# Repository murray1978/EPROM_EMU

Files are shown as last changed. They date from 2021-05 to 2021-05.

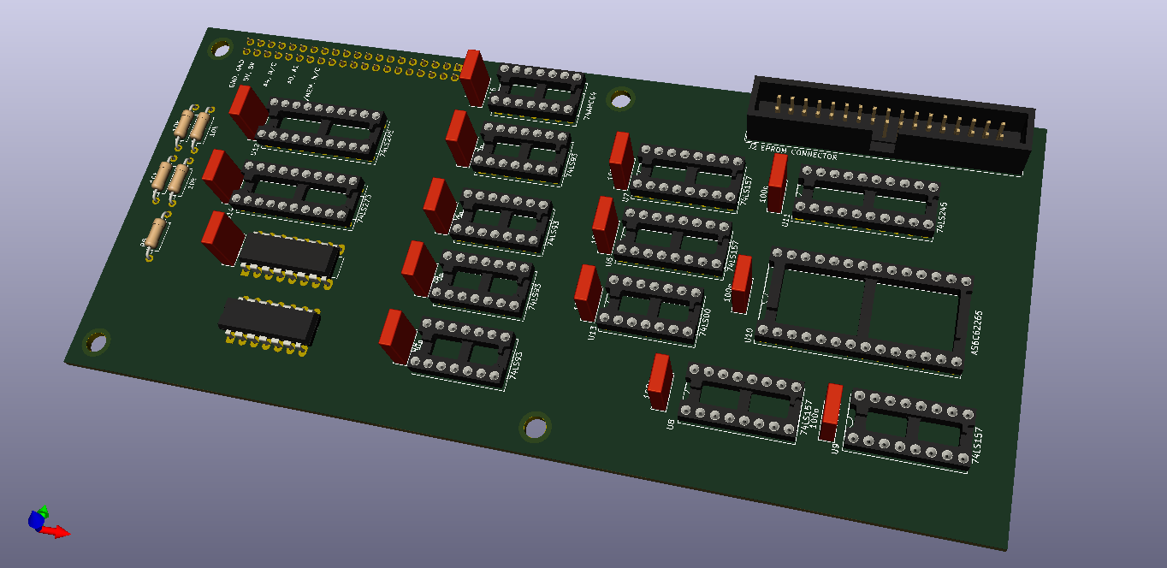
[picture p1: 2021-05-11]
Version 2/wmuv1.1.png

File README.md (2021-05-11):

# EPROM_EMU
EPROM Emulator for [Sergey's](http://www.malinov.com/Home/sergeys-projects/minimax8085) 8085 board.
Second revison is in progress, 12/5/21, check the readme in version two for errors on the board.

## Programming
The monitor rom can be used to upload the emulator code for the board.
Install the battery backup on to the 8085 borad then you will not need to upload each time you need to use the board.

## Source
As is where is, one carfull lady owner.
Some functions are copied from the monitor code, but it does relie on the monitor rom to setup the 8251 UART before use.
Code is just an outline now with a few ideas in comments.

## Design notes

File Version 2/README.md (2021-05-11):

# EPROM_EMU
EPROM Emulator for [Sergey's](http://www.malinov.com/Home/sergeys-projects/minimax8085) 8085 board, This is the Second revision.

## Mistakes
1. IC1 (74LS137), Pins 9 and 7, will never get triggered, the correct connections are pins 15 and 14.
   Fix with a solder a jumper bridge between 9 to 15 and 7 to 14. Schmatic is correct

## Substitutions 
1. U1 can be replaced with a 74LS138
2. the RAM, U10 as6c62256, can be replaced with cy62256? need to confirm pinout.

## Programming
The monitor rom can be used to upload the emulator code for the board.
Install the battery backup on to the 8085 borad then you will not need to upload each time you need to use the board.

## Source
As is where is, one carfull lady owner.
Some functions are copied from the monitor code, but it does relie on the monitor rom to setup the 8251 UART before use.
Code is just an outline now with a few ideas in comments.

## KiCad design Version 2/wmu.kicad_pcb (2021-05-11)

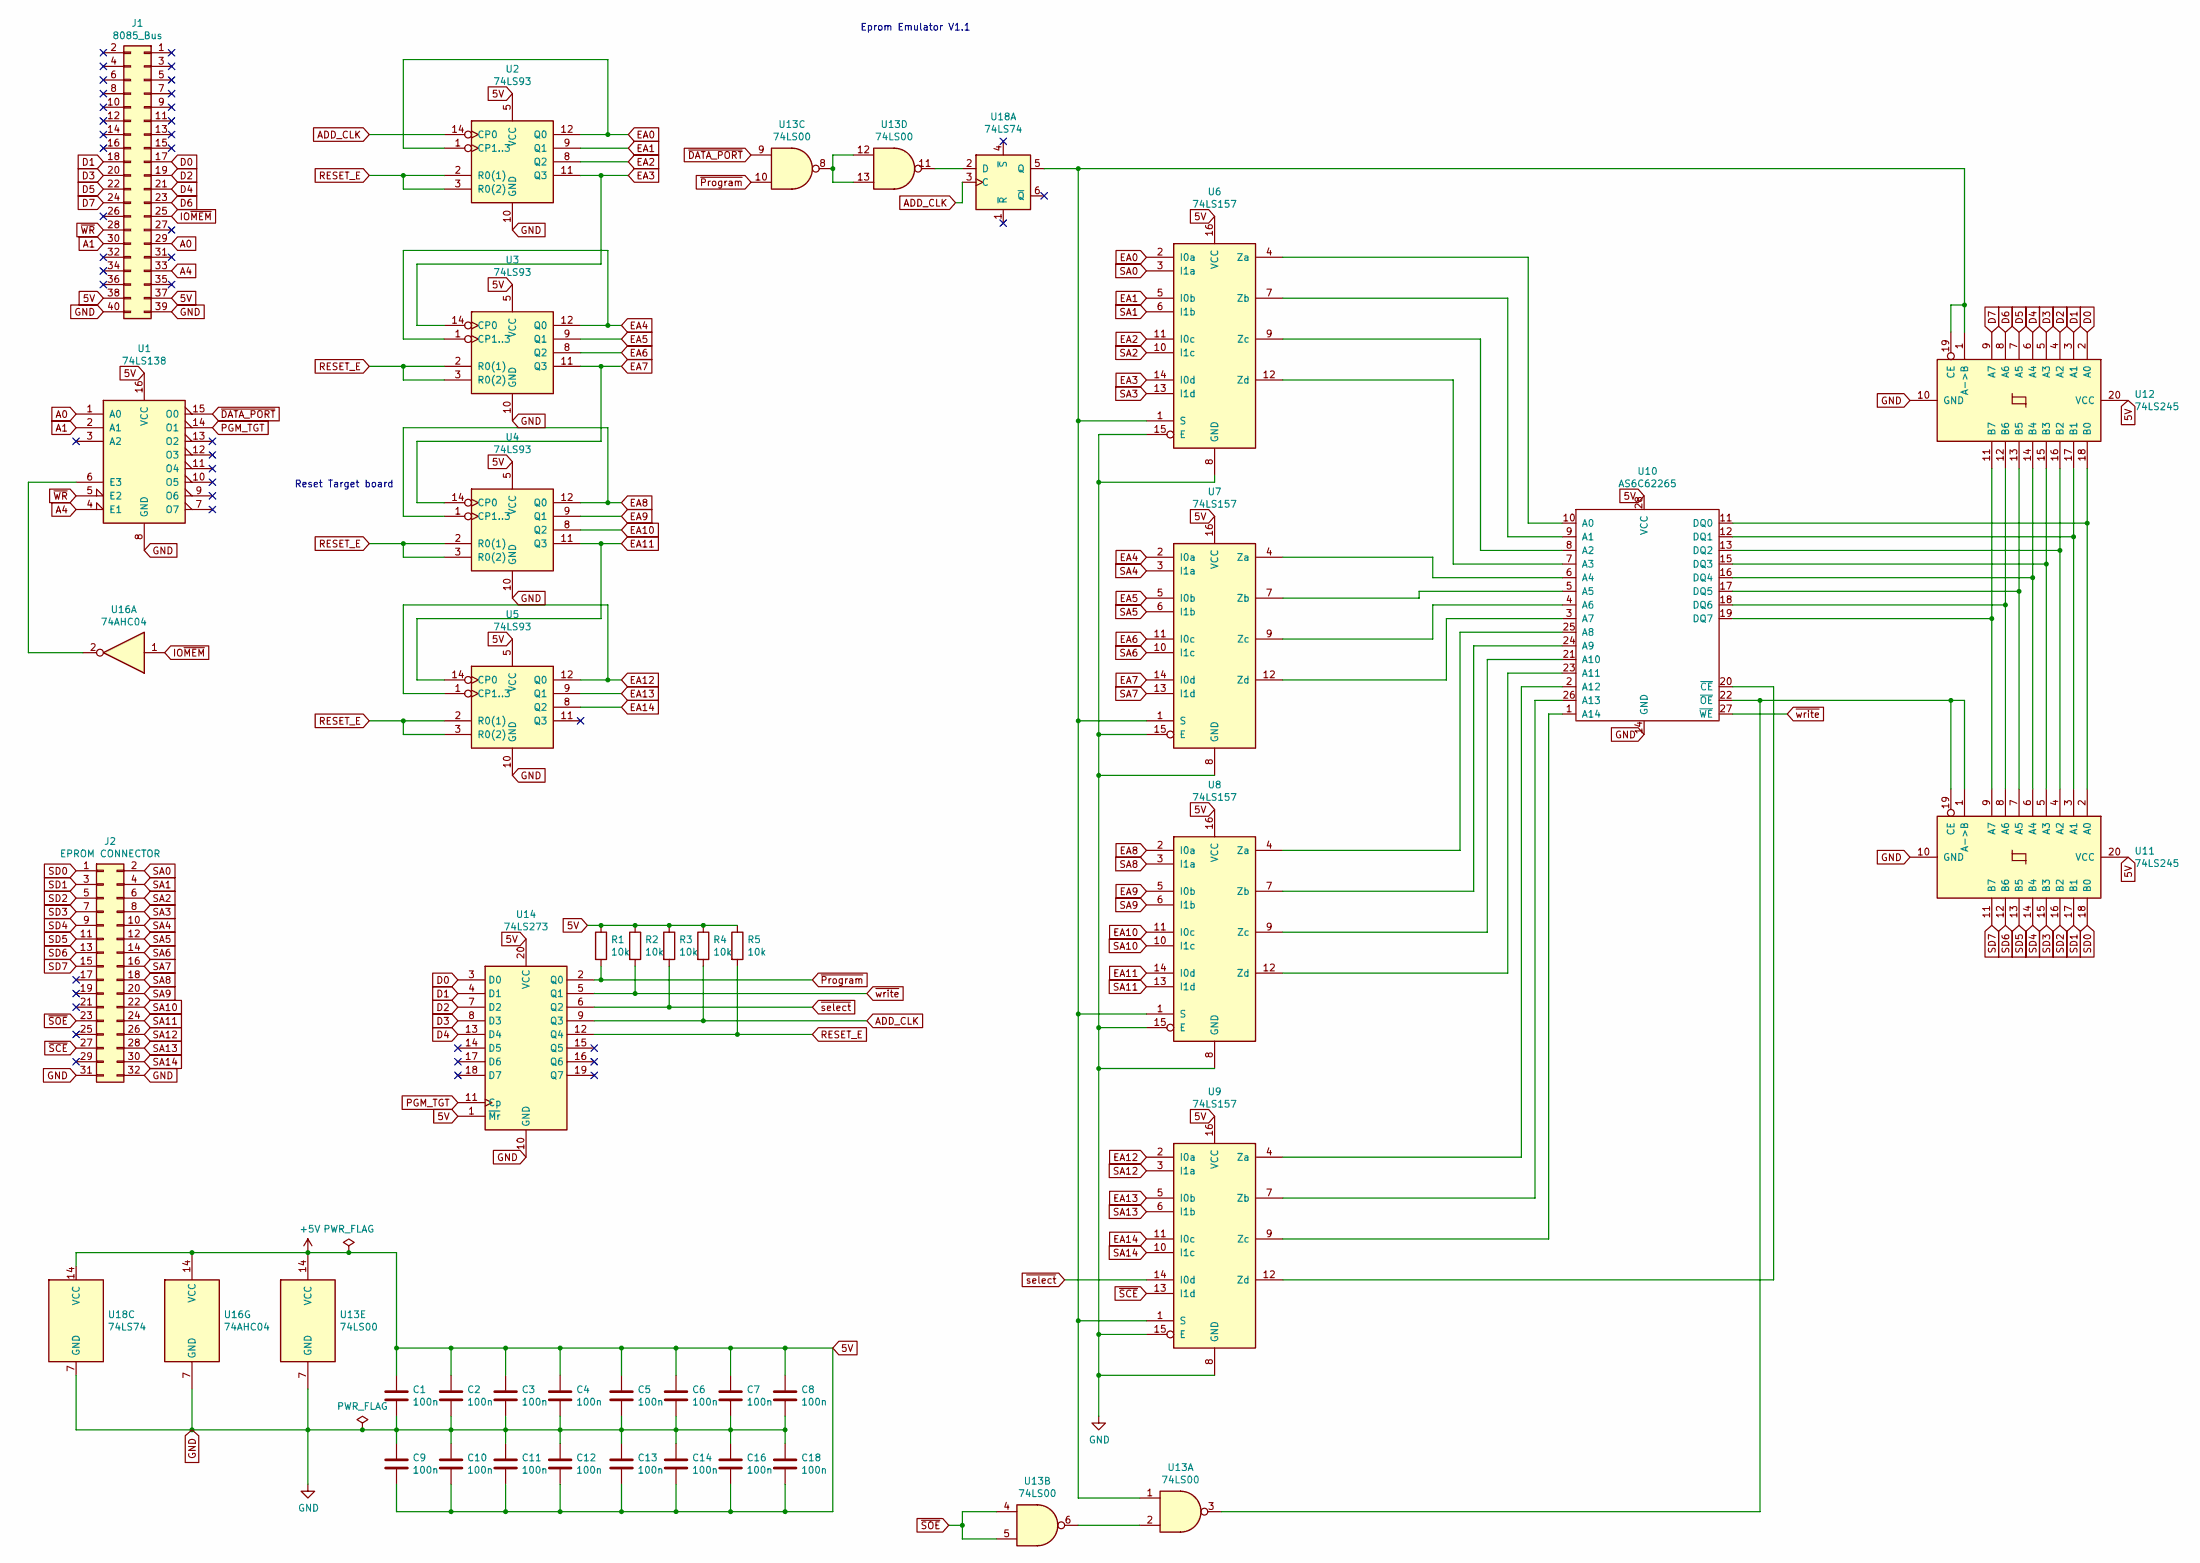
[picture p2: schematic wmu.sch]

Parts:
C1, C2, C3, C4, C5, C6, C7, C8, C9, C10, C11, C12, C13, C14, C16, C18: 100n; C_Rect_L7.0mm_W2.5mm_P5.00mm
J1: 8085_Bus; PinSocket_2x20_P2.54mm_Vertical
J2: EPROM CONNECTOR; IDC-Header_2x17_P2.54mm_Vertical
R1, R2, R3, R4, R5: 10k; R_Axial_DIN0207_L6.3mm_D2.5mm_P10.16mm_Horizontal
U1: 74LS138; DIP-16_W7.62mm_LongPads
U2, U3, U4, U5: 74LS93; DIP-14_W7.62mm_Socket
U6, U7, U8, U9: 74LS157; DIP-16_W7.62mm_Socket
U10: AS6C62265; DIP-28_W15.24mm_Socket
U11, U12: 74LS245; DIP-20_W7.62mm_Socket
U13: 74LS00; DIP-14_W7.62mm_Socket
U14: 74LS273; DIP-20_W7.62mm_Socket
U16: 74AHC04; DIP-14_W7.62mm_Socket
U18: 74LS74; DIP-14_W7.62mm_LongPads

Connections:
5V: C1.1, C2.1, C3.1, C4.1, C5.1, C6.1, C7.1, C8.1, C9.2, C10.2, C11.2, C12.2, C13.2, C14.2, C16.2, C18.2, J1.37, J1.38, R1.1, R2.1, R3.1, R4.1, R5.1, U1.16 (VCC), U2.5 (VCC), U3.5 (VCC), U4.5 (VCC), U5.5 (VCC), U6.16 (VCC), U7.16 (VCC), U8.16 (VCC), U9.16 (VCC), U10.28 (VCC), U11.20 (VCC), U12.20 (VCC), U13.14 (VCC), U14.1 (~Mr), U14.20 (VCC), U16.14 (VCC), U18.14 (VCC)
A0: J1.29, U1.1 (A0)
A1: J1.30, U1.2 (A1)
A4: J1.33, U1.4 (E1)
ADD_CLK: R4.2, U2.14 (CP0), U14.9 (Q3), U18.3 (C)
D0: J1.17, U12.2 (A0), U14.3 (D0)
D1: J1.18, U12.3 (A1), U14.4 (D1)
D2: J1.19, U12.4 (A2), U14.7 (D2)
D3: J1.20, U12.5 (A3), U14.8 (D3)
D4: J1.21, U12.6 (A4), U14.13 (D4)
D5: J1.22, U12.7 (A5)
D6: J1.23, U12.8 (A6)
D7: J1.24, U12.9 (A7)
EA0: U2.1 (CP1..3), U2.12 (Q0), U6.2 (I0a)
EA1: U2.9 (Q1), U6.5 (I0b)
EA2: U2.8 (Q2), U6.11 (I0c)
EA3: U2.11 (Q3), U3.14 (CP0), U6.14 (I0d)
EA4: U3.1 (CP1..3), U3.12 (Q0), U7.2 (I0a)
EA5: U3.9 (Q1), U7.5 (I0b)
EA6: U3.8 (Q2), U7.11 (I0c)
EA7: U3.11 (Q3), U4.14 (CP0), U7.14 (I0d)
EA8: U4.1 (CP1..3), U4.12 (Q0), U8.2 (I0a)
EA9: U4.9 (Q1), U8.5 (I0b)
EA10: U4.8 (Q2), U8.11 (I0c)
EA11: U4.11 (Q3), U5.14 (CP0), U8.14 (I0d)
EA12: U5.1 (CP1..3), U5.12 (Q0), U9.2 (I0a)
EA13: U5.9 (Q1), U9.5 (I0b)
EA14: U5.8 (Q2), U9.11 (I0c)
GND: C1.2, C2.2, C3.2, C4.2, C5.2, C6.2, C7.2, C8.2, C9.1, C10.1, C11.1, C12.1, C13.1, C14.1, C16.1, C18.1, J1.39, J1.40, J2.31, J2.32, U1.8 (GND), U2.10 (GND), U3.10 (GND), U4.10 (GND), U5.10 (GND), U6.8 (GND), U6.15 (E), U7.8 (GND), U7.15 (E), U8.8 (GND), U8.15 (E), U9.8 (GND), U9.15 (E), U10.14 (GND), U11.10 (GND), U12.10 (GND), U13.7 (GND), U14.10 (GND), U16.7 (GND), U18.7 (GND)
IO~MEM: J1.25, U16.1
unnamed: U1.6 (E3), U16.2
unnamed: U9.9 (Zc), U10.1 (A14)
unnamed: U9.4 (Za), U10.2 (A12)
unnamed: U7.12 (Zd), U10.3 (A7)
unnamed: U7.9 (Zc), U10.4 (A6)
unnamed: U7.7 (Zb), U10.5 (A5)
unnamed: U7.4 (Za), U10.6 (A4)
unnamed: U6.12 (Zd), U10.7 (A3)
unnamed: U6.9 (Zc), U10.8 (A2)
unnamed: U6.7 (Zb), U10.9 (A1)
unnamed: U6.4 (Za), U10.10 (A0)
unnamed: U10.11 (DQ0), U11.2 (A0), U12.18 (B0)
unnamed: U10.12 (DQ1), U11.3 (A1), U12.17 (B1)
unnamed: U10.13 (DQ2), U11.4 (A2), U12.16 (B2)
unnamed: U10.15 (DQ3), U11.5 (A3), U12.15 (B3)
unnamed: U10.16 (DQ4), U11.6 (A4), U12.14 (B4)
unnamed: U10.17 (DQ5), U11.7 (A5), U12.13 (B5)
unnamed: U10.18 (DQ6), U11.8 (A6), U12.12 (B6)
unnamed: U10.19 (DQ7), U11.9 (A7), U12.11 (B7)
unnamed: U9.12 (Zd), U10.20 (~CE)
unnamed: U8.9 (Zc), U10.21 (A10)
unnamed: U10.22 (~OE), U11.1 (A->B), U11.19 (CE), U13.3
unnamed: U8.12 (Zd), U10.23 (A11)
unnamed: U8.7 (Zb), U10.24 (A9)
unnamed: U8.4 (Za), U10.25 (A8)
unnamed: U9.7 (Zb), U10.26 (A13)
unnamed: U6.1 (S), U7.1 (S), U8.1 (S), U9.1 (S), U12.1 (A->B), U12.19 (CE), U13.1, U18.5 (Q)
unnamed: U13.2, U13.6
unnamed: U13.11, U18.2 (D)
unnamed: U13.8, U13.12, U13.13
PGM_TGT: U1.7 (O7), U1.14 (O1), U14.11 (Cp)
RESET_E: R5.2, U2.2 (R0(1)), U2.3 (R0(2)), U3.2 (R0(1)), U3.3 (R0(2)), U4.2 (R0(1)), U4.3 (R0(2)), U5.2 (R0(1)), U5.3 (R0(2)), U14.12 (Q4)
SA0: J2.2, U6.3 (I1a)
SA1: J2.4, U6.6 (I1b)
SA2: J2.6, U6.10 (I1c)
SA3: J2.8, U6.13 (I1d)
SA4: J2.10, U7.3 (I1a)
SA5: J2.12, U7.6 (I1b)
SA6: J2.14, U7.10 (I1c)
SA7: J2.16, U7.13 (I1d)
SA8: J2.18, U8.3 (I1a)
SA9: J2.20, U8.6 (I1b)
SA10: J2.22, U8.10 (I1c)
SA11: J2.24, U8.13 (I1d)
SA12: J2.26, U9.3 (I1a)
SA13: J2.28, U9.6 (I1b)
SA14: J2.30, U9.10 (I1c)
SD0: J2.1, U11.18 (B0)
SD1: J2.3, U11.17 (B1)
SD2: J2.5, U11.16 (B2)
SD3: J2.7, U11.15 (B3)
SD4: J2.9, U11.14 (B4)
SD5: J2.11, U11.13 (B5)
SD6: J2.13, U11.12 (B6)
SD7: J2.15, U11.11 (B7)
~DATA_PORT: U1.9 (O6), U1.15 (O0), U13.9
~Program: R1.2, U13.10, U14.2 (Q0)
~SCE: J2.27, U9.13 (I1d)
~SOE: J2.23, U13.4, U13.5
~WR: J1.28, U1.5 (E2)
~select: R3.2, U9.14 (I0d), U14.6 (Q2)
~write: R2.2, U10.27 (~WE), U14.5 (Q1)

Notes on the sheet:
Reset Target board
Eprom Emulator V1.1

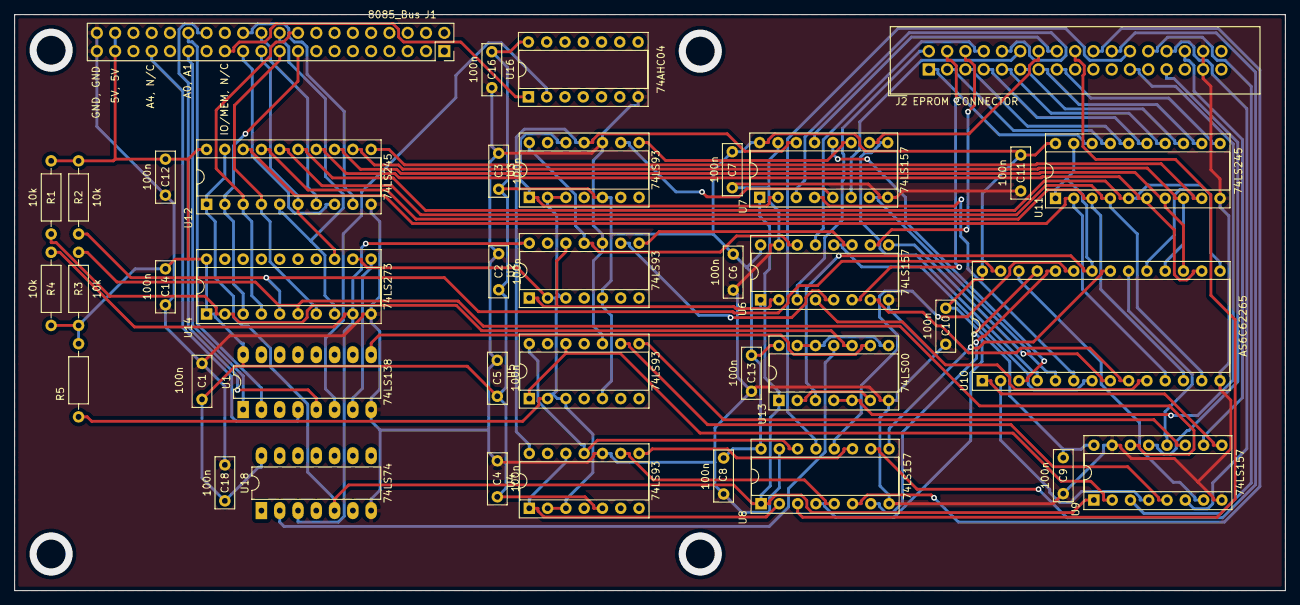
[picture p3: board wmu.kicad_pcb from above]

Board: 2 copper layers, 176.5 x 80.0 mm, 39 parts (0 on the bottom side), 92 nets.

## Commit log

2020-11-01 Added Schematic and board
    Initial Commit
    [wmu.kicad_pcb, wmu.sch]
2021-05-11 Update README.md
    Added note about incorrect pin out for IC1
2021-05-11 Update for second version
    [EpromEmuV1.1.kicad_pcb, wmu.kicad_pcb, wmu.sch]
2021-05-12 PCB update
    Fixed issue with incorrect pin connections on IC1
    [wmu.dsn]
